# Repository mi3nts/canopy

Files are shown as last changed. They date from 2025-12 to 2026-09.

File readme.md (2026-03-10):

# CANOPY Community Avian and AirQuality Network for Observing Pollution Year-round
Contains firmware for the Community Avian and AirQuality Network for Observing Pollution Year-round(CANOPY)

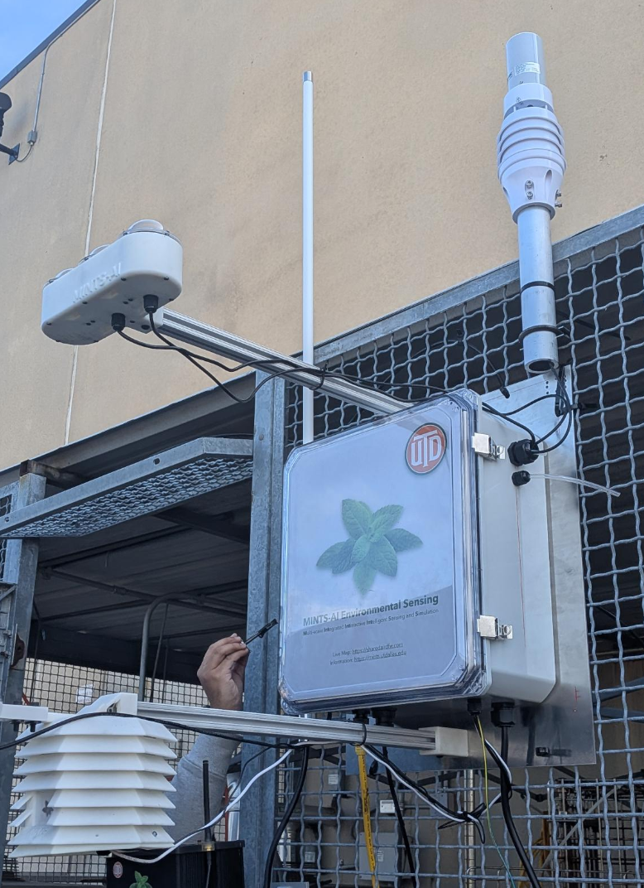
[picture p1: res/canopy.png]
Deployed Canopy


## Suggested Framework 

### 📋 Summary
This system design leverages an **Odroid** as a powerful Edge IoT node, integrating local data collection, processing, and resilient cloud synchronization. All local services and custom sensor readers are managed via **Git repositories** for version control and streamlined deployments. The system ensures continuous operation during internet outages by storing data locally and syncing to the cloud when connectivity is restored, while also publishing live data to the cloud via MQTT.

---

## Electrical Data Parts List
- **Raspberry Pi Zero 2W** (on [Dream V2.0 PCB Board](https://github.com/mi3nts/PCBMints2025) or later)
    - OPC-N3 
    - SJH-5A Methane Sensor (Not working on Dream V2.0 or earlier)
    - BME280 
    - IPS7100
    - COZIR AH-E-1
- **2x Odroid N2**
    - RS-FSXCS Anemometer
    - AS7265X
    - LTR390
    - SEN0463 Radiation sensor
    - 2x G-MOUSE USB GPS
    - USB Camera
    - USB Microphone
- **2x Arduino Boards**
    - One for managing the relays (receives input from odroidHeartbeat.py)
        - Ensure step up to 5V if board outputs 3.3V
    - One for digitalizing analog outputs from SEN0463

---

## Data Management
- **Git-Managed Dockerized Sensor Readers**: Python containers pulled from Git, reading sensors and publishing data via MQTT.
- **Git-Managed Local Services**:
  - **Mosquitto (MQTT Broker)**: Manages local messaging.
  - **Node-RED**: Handles data routing, automation, and local storage to InfluxDB.
  - **InfluxDB (Local)**: Buffers time-series data at the edge.
  - **Telegraf**: Continuously syncs local InfluxDB data to Cloud InfluxDB.
  - **Grafana**: Provides edge visualization for real-time monitoring without relying on cloud access.
- **Cloud Backend**: Centralized Node-RED, InfluxDB, and Grafana for real-time processing, long-term storage, and visualization.

---

### 🌐 Data Flow
1. Sensors connected to Odroid are read by Dockerized Python sensor readers deployed from Git - The current repo.
2. Sensor data is published to:
   - **Local MQTT Broker** for edge processing.
   - **Cloud MQTT Broker** for real-time cloud ingestion.
3. Node-RED (Edge) subscribes to local MQTT, processes data, and stores it in local InfluxDB.
4. Telegraf syncs buffered data from local InfluxDB to Cloud InfluxDB.
5. Cloud Node-RED and Grafana handle advanced workflows and visualization.

---

### 🛡️ Key Features
- **Git-Managed Deployments**: Version control for all services and sensor readers.
- **Offline Resilience**: Full functionality without internet.
- **Live Data Streaming**: Real-time data published to cloud via MQTT.
- **Automated Cloud Sync**: Telegraf ensures data consistency between edge and cloud.
- **Modular & Scalable**: Docker-based deployment for easy management.
- **Flexible Automation**: Node-RED enables custom logic and integrations.

---

## 🚀 Deployment Steps
1. Clone Git repositories for local services and sensor readers.
2. Deploy Docker Compose stack on Odroid (MQTT, Node-RED, InfluxDB, Telegraf, Grafana).
3. Run sensor reader containers from Git.
4. Configure Node-RED flows for data handling.
5. Set up Telegraf for continuous cloud sync.
6. Deploy local Grafana for edge-based dashboards and visualization.
7. Access cloud Node-RED and Grafana for real-time monitoring and dashboards.

### Odroid N2 Pinout Connection
- **Connection for 1B
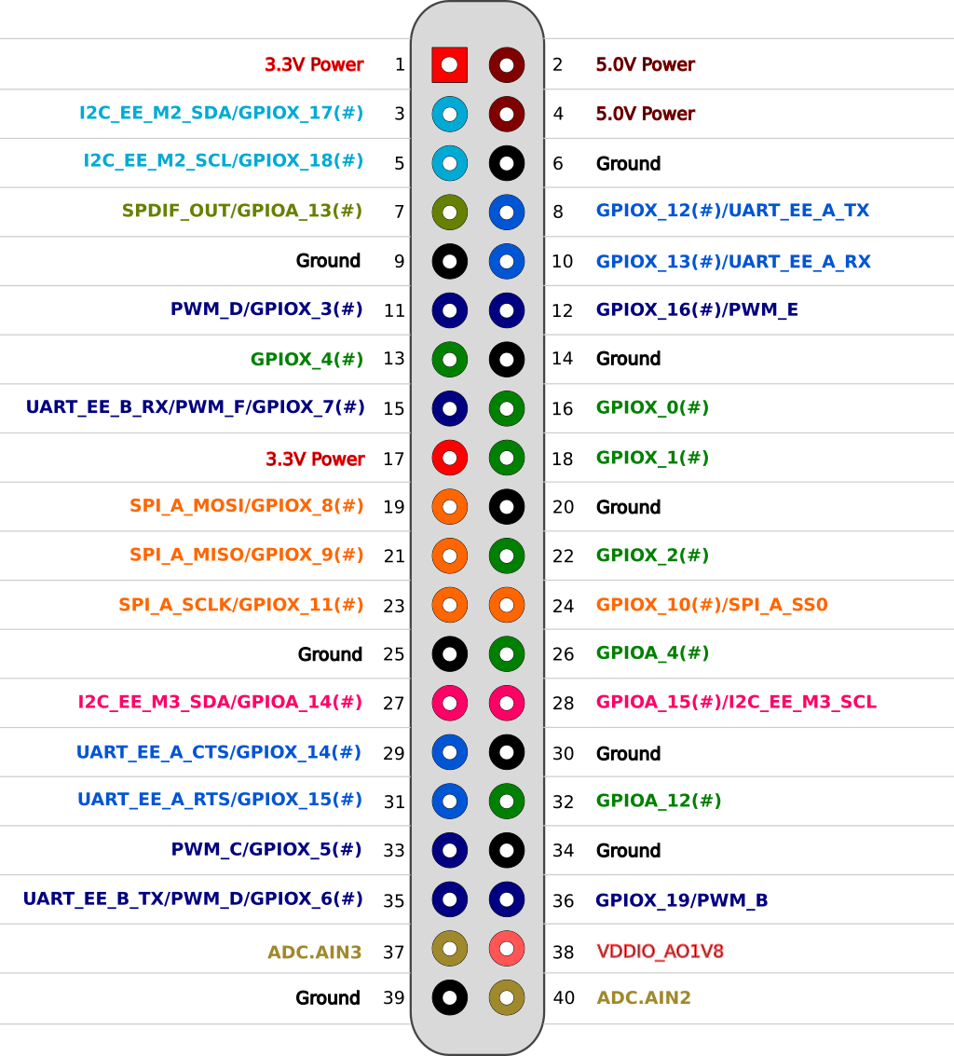
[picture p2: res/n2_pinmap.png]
Pinout Diagram
-

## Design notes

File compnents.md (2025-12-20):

# Components

## Main Compute Units 

- **Odroid N2+**

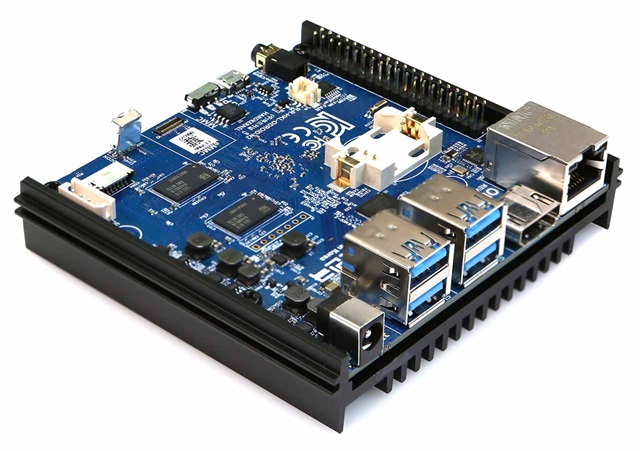
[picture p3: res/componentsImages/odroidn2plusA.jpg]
Odroid N2+
  

- **XIAO ESP32 S3**
  
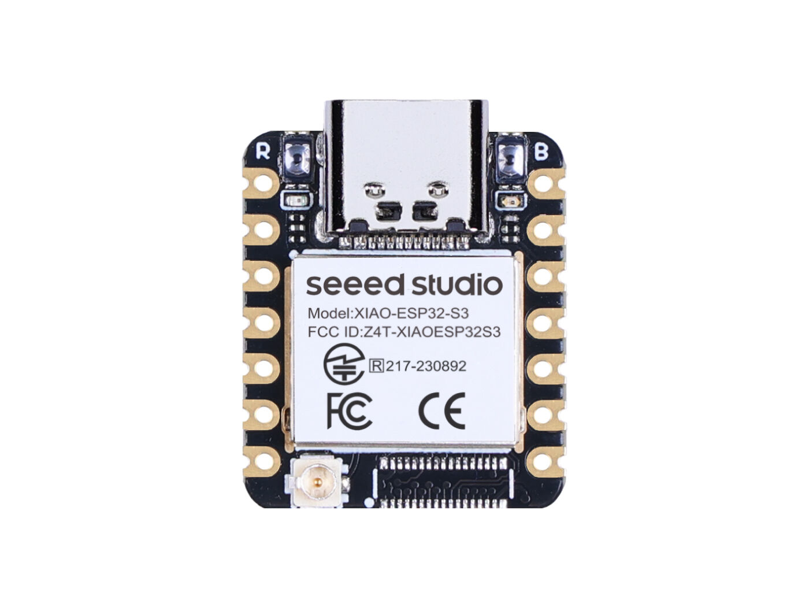
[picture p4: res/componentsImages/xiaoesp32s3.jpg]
XIAO ESP32 S3
   

- **Arduino Nano 33 BLE** 
  
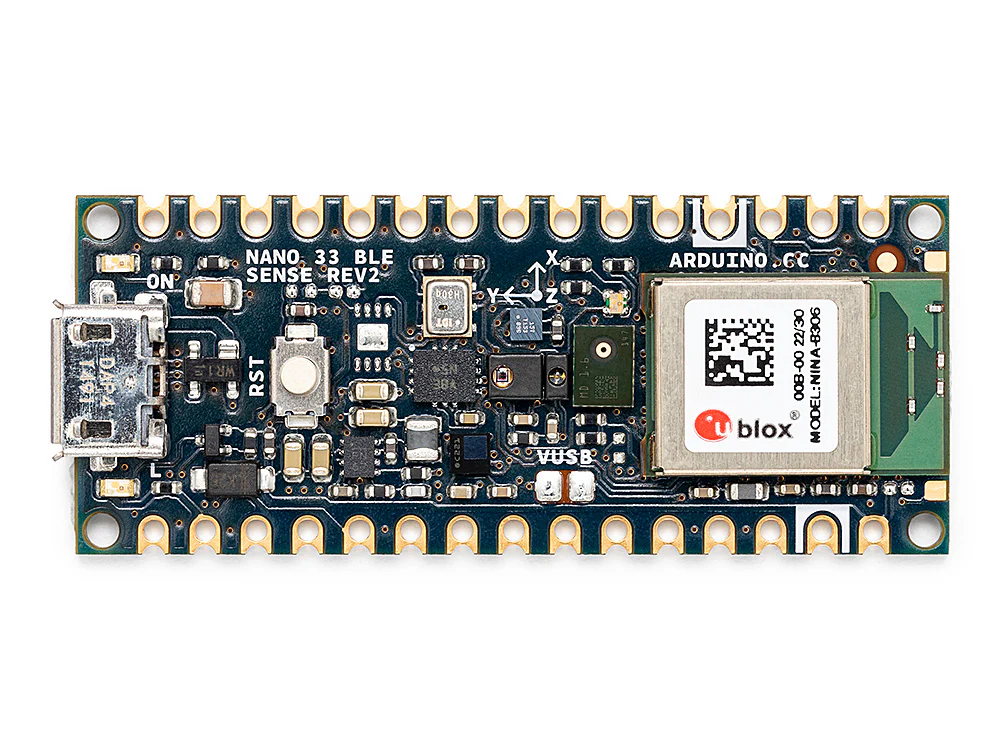
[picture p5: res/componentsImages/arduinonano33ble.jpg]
Arduino Nano 33 BLE
  

## Sensor Modules

- **DFRobot SEN0463** 
  
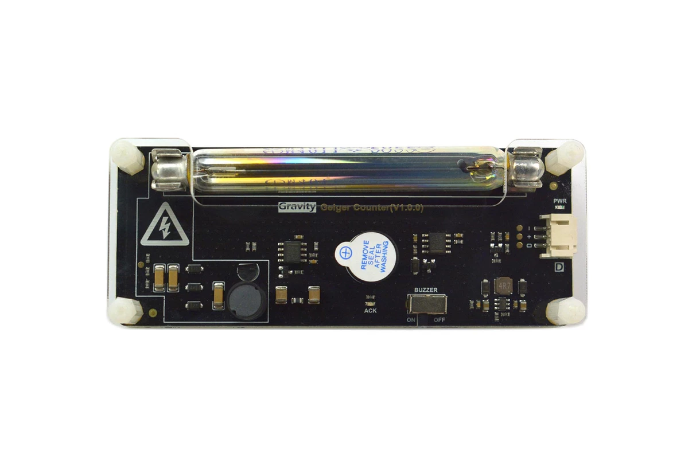
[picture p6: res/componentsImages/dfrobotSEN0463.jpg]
DFRobot SEN0463
   

- **Ozone Sensor** 
  
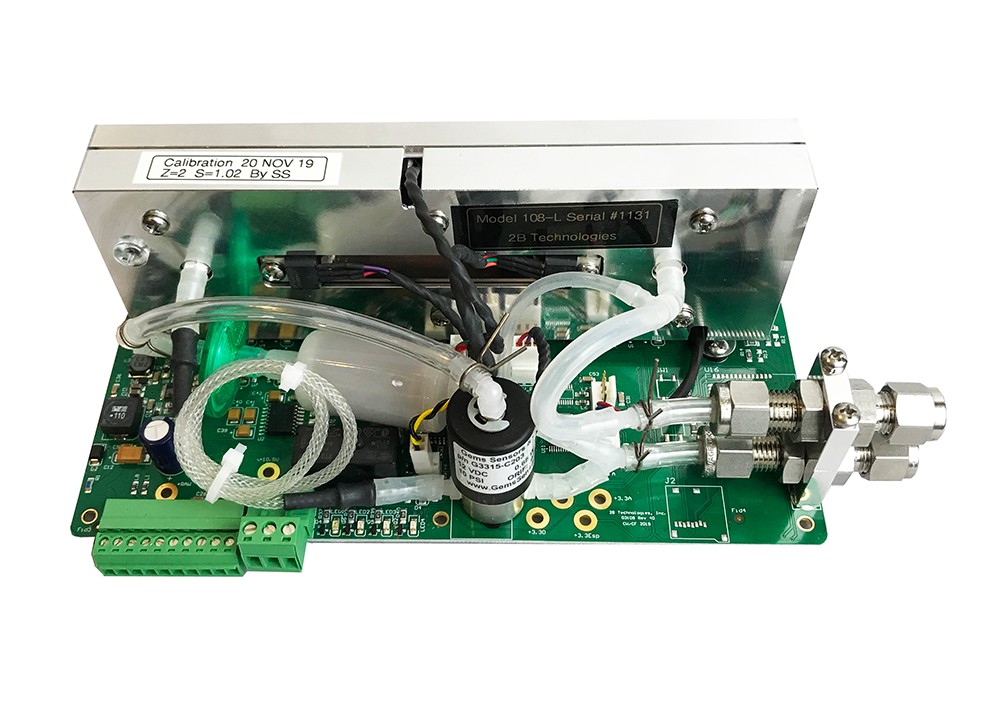
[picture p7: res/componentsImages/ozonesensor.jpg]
Ozone Sensor
  

- **GPS Module** 
  
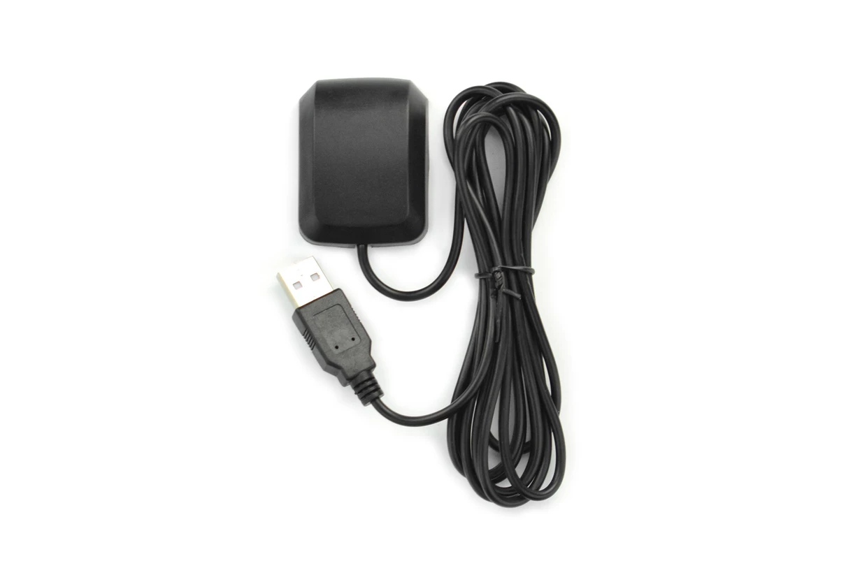
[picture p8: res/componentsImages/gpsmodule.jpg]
GPS Module
  

 ## Network Modules

- **Network Switch** (4 port) 
  
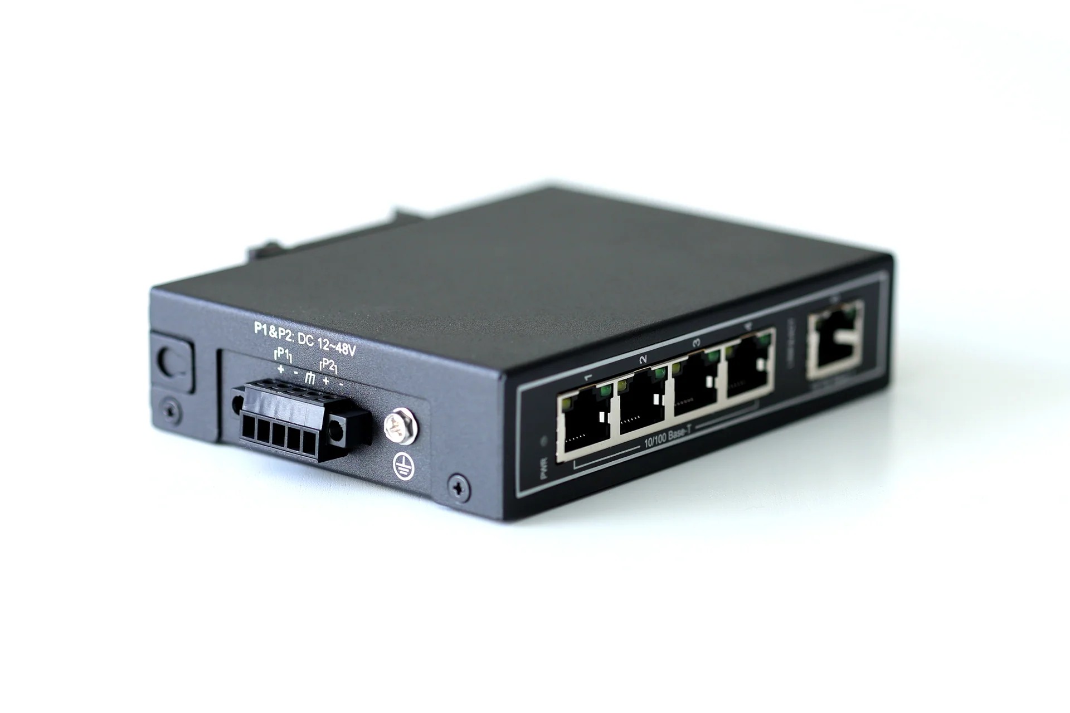
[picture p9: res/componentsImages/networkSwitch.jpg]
Network Switch
  

- **LoRaWAN Gateway** 
  
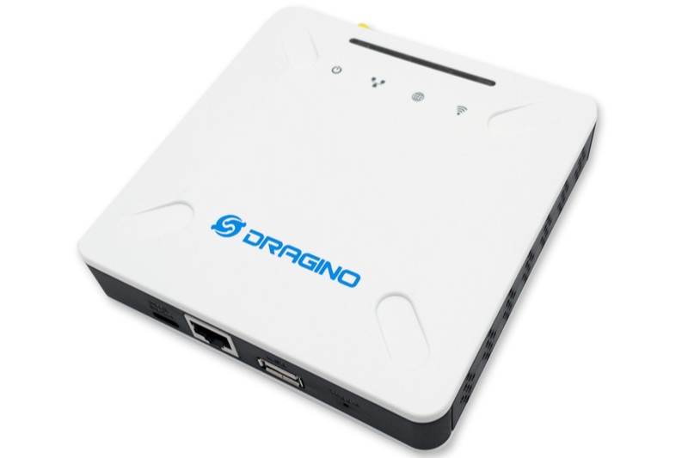
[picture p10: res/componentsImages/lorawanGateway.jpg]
LoRaWAN Gateway
  

## Power Modules
- **12V 3A AC to DC Power Supply** 
  
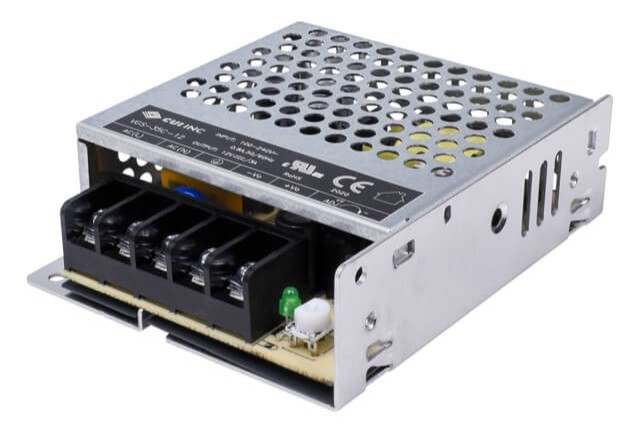
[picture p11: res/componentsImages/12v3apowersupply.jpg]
12V 3A AC to DC Power Supply
  

- **5V 5A AC to DC Power Supply** 
  
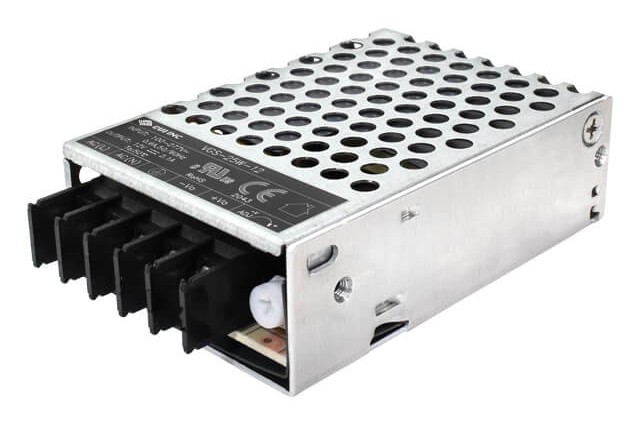
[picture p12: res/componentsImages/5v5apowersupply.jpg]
5V 5A AC to DC Power Supply
  

- **Solid State Relay 4 Channel** 
  
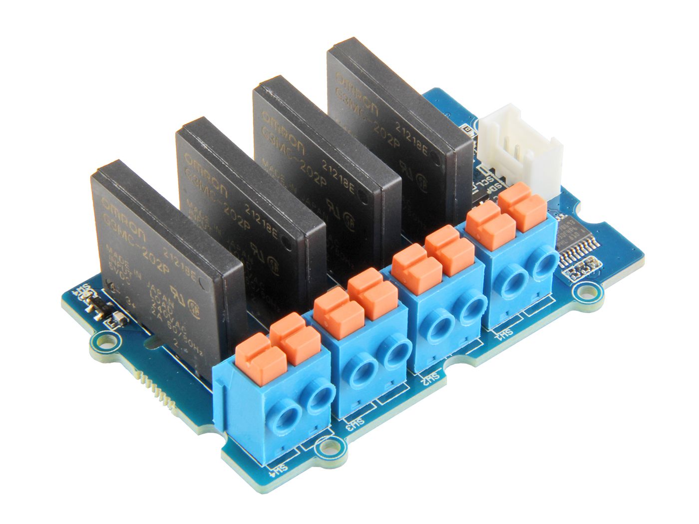
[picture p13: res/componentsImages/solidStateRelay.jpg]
Solid State Relay 4 Channel


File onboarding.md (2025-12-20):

# 🚀 Odroid N2+ Onboarding Guide

## 📥 OS Installation on SD Card  
1. Download the Odroid N2+ OS from [this link](https://wiki.odroid.com/odroid-n2/os_images/ubuntu/20220228).  
2. Use [Etcher](https://etcher.balena.io/) to flash the image onto your SD card.

---

## 👤 User Account Setup
1. Connect to the Odroid via a [UART Module](https://ameridroid.com/products/usb-uart-2-module-kit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).
2. Login using default credentials:
   - **Username:** `odroid`
   - **Password:** `odroid`
3. Create a new user:
   ```bash
   sudo adduser teamlary
   ```
4. Grant sudo privileges:
   ```bash
   sudo usermod -aG sudo teamlary
   ```
5. Switch to the new user:
   ```bash
   su teamlary
   ```
6. Create default directories:
   ```bash
   xdg-user-dirs-update
   ```
7. Verify sudo access:
   ```bash
   sudo whoami
   ```
   Expected output: `root`
8. Change the user password:
   ```bash
   passwd
   ```
9. Remove the default `odroid` user:
   ```bash
   sudo su
   userdel odroid
   userdel -r odroid
   ```

---

## 🕒 Time Zone & Clock Configuration

Ensure an RTC module is installed. Perform the following on all Linux-based MINTS nodes:

1. Check current time settings:
   ```bash
   timedatectl status
   ```
2. Set system time zone to UTC:
   ```bash
   timedatectl set-timezone UTC
   ```
3. Configure RTC to use UTC:
   ```bash
   timedatectl set-local-rtc 0
   ```
4. Enable NTP synchronization:
   ```bash
   timedatectl set-ntp true
   ```

✅ After completion, verify synchronization using:
```bash
timedatectl status
```

*Reference:* [Tecmint Guide](https://www.tecmint.com/set-time-timezone-and-synchronize-time-using-timedatectl-command/)

### 🌐 No Internet? Sync Time from RTC
If no internet is available, configure automatic RTC sync via `/etc/rc.local`:

1. Edit the file:
   ```bash
   sudo nano /etc/rc.local
   ```

2. Add the following script:

   ```bash
   #!/bin/bash

   if [ -f /aafirstboot ]; then 
       /aafirstboot start
   fi

   if ping -c 1 8.8.8.8 >/dev/null 2>&1; then
       echo "$(date): Internet detected - Syncing system clock..."
       sudo systemctl restart systemd-timesyncd
       sleep 10

       if timedatectl | grep -q "System clock synchronized: yes"; then
           echo "$(date): Writing system time to RTC..."
           hwclock -w
       else
           echo "$(date): System clock not synced yet. Skipping RTC update." >> /var/log/time_sync.log
       fi
   else
       echo "No internet connection: Syncing system time from RTC..."
       hwclock -s
   fi

   exit 0
   ```

**Behavior:**
- 🌐 **With Internet:** Sync system clock via NTP and update RTC.
- 🚫 **Without Internet:** Restore system clock from RTC.

---

## 🌐 DWAgent Remote Access Setup

### 📥 Installation
1. On your DWService account, create a new agent.
2. Download the installer for Ubuntu:
   ```bash
   wget https://www.dwservice.net/download/dwagent.sh
   chmod +x dwagent.sh 
   sudo ./dwagent.sh
   ```
3. During installation, select **Installer Code** and enter the provided code to register the agent.
4. Complete the setup by copying the agent code to your system.

### ❌ Uninstallation
To remove DWAgent:
```bash
sudo bash /usr/share/dwagent/native/uninstall
```
Follow the on-screen instructions to complete the uninstallation.

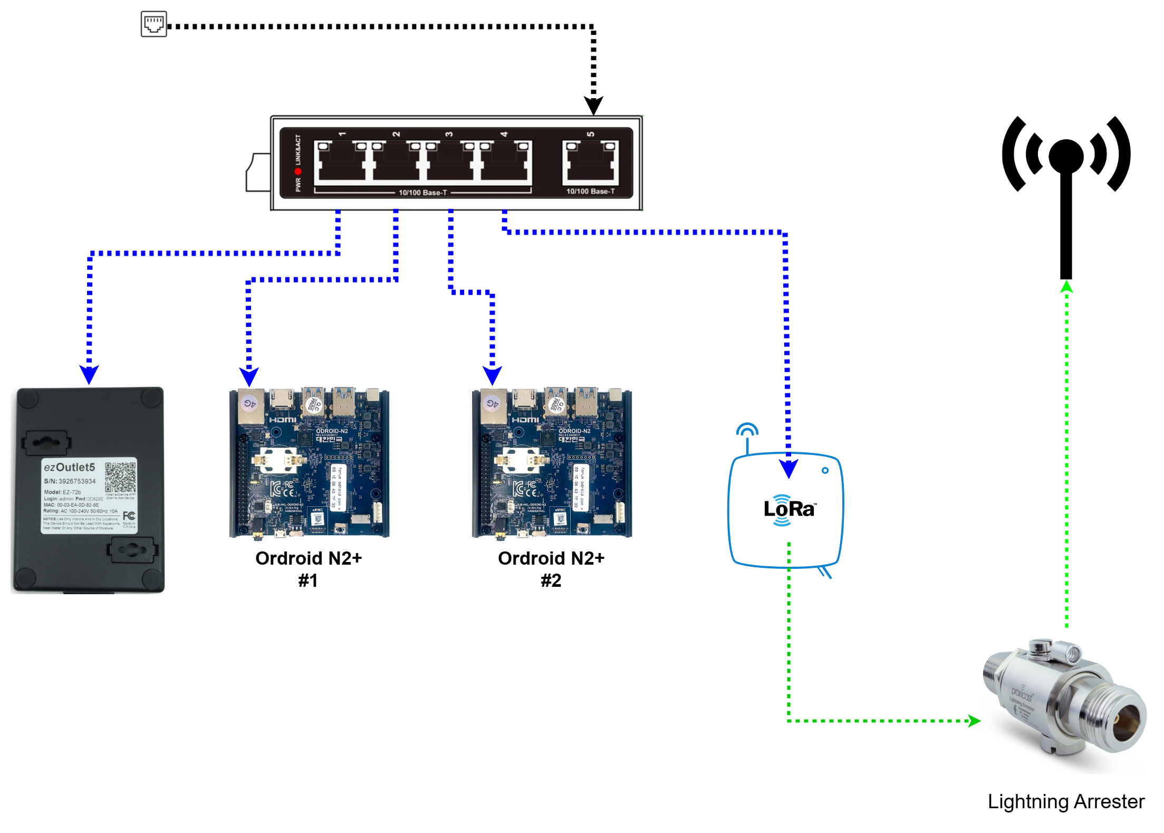
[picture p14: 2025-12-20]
res/CanopyNetworkDiagram.drawio.png

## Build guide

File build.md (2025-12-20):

# Build 

## Components
| Type | Component Name | Quantity | Canopy 1 | Canopy 2 | Canopy 3 |
| :--- | :--- | :---: | :---: | :---: | :---: |
| **Compute Modules** | [**Odroid N2+**](https://www.hardkernel.com/shop/odroid-n2-with-4gbyte-ram-2/) | 2 | ✅ | ✅ | ✅ |
|  | [**Arduino Nano 33 BLE**](https://store.arduino.cc/products/nano-33-ble-sense-rev2) | 1 | ✅ | ✅ | ❌ |
|  | [**XIAO ESP32 S3**](https://www.seeedstudio.com/XIAO-ESP32S3-p-5627.html) | 1 | ✅ | ✅ | ❌ |
| **Sensor Modules** | [**DFRobot SEN0463**](https://www.dfrobot.com/product-2547.html) | 1 | ✅ | ✅ | ❌ |
|  | [**Ozone Sensor**](https://2btech.io/items/industrial-ozone-monitors/model-108-l-ozone-monitor/) | 1 | ✅ | ✅ | ✅ |
| **Network Modules** | [**Network Switch** (4 port)](https://wiwav.com/products/wdh-5et-dc) | 1 | ✅ | ✅ | ✅ |
|  | [**LoRaWAN Gateway**](https://www.dragino.com/products/lora-lorawan-gateway/item/228-lps8v2.html) | 1 | ✅ | ✅ | ✅ |
| **Power Modules** | [**12V 3A AC to DC Power Supply**](https://www.digikey.com/en/products/detail/cui-inc/vgs-35c-12/13538494) | 3 | ✅ | ✅ | ✅ |
|  | [**5V 5A AC to DC Power Supply**](https://www.digikey.com/en/products/detail/cui-inc/VGS-25W-5/13981829) | 2 | ✅ | ✅ | ✅ |
|  | [**Solid State Relay 4 Channel**](https://www.seeedstudio.com/Grove-4-Channel-Solid-State-Relay.html) | 1 | ✅ | ✅ | ❌ |
|  | [**ezOutlet5**](https://www.proxicast.com/shopping/ezoutlet5.html) | 1 | ✅ | ✅ | ✅ |
| **Glands** | [**Power Gland**](https://www.digikey.com/en/products/detail/adam-tech/PG-2-3/10000000) | 1 | ✅ | ✅ | ✅ |
|  | [**Ethernet Gland**](https://www.digikey.com/en/products/detail/conxall-switchcraft/dcp-rj6st-f/3909464) | 1 | ✅ | ✅ | ✅ |
| **CNC & 3D Printed Parts** | **Acrylic Base** | 1 | ✅ | ✅ | ✅ |
|  | **Odroid N2+ Bases** | 2 | ✅ | ✅ | ✅ |
|  | **GPS Enclosure** | 1 | ✅ | ✅ | ✅ |
|  | **Geiger(SEN0463) Enclosure** | 1 | ✅ | ✅ | ⏳ |
|  | **Ozone Pump Base** | 1 | ✅ | ✅ | ✅ |
|  | **LoRaWAN Gateway Holder** | 1 | ✅ | ✅ | ✅ |
|  | **ezOutlet5 Holder** | 1 | ✅ | ✅ | ✅ |
|  | **5V Power Supply Base** | 2 | ✅ | ✅ | ✅ |
|  | **12V Power Supply Base** | 3 | ✅ | ✅ | ✅ |
|  | **Solid State Relay Base** | 1 | ✅ | ✅ | ❌ |
|  | **Lightning Arrester Enclosure** | 1 | ✅ | ✅ | ✅ |
| **Miscellaneous** | [**Lightning Arrestor**](https://www.waveform.com/products/sma-lightning-arrestor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) | 1 | ✅ | ✅ | ✅ |
|  | [**GPS Module**](https://www.dfrobot.com/product-2212.html?srsltid=AfmBOopC3ACS4fteI6YBTIDWjCWQ0hfJIGSxyhN_UdGwQtrTQll43zKa) | 2 | ✅ | ✅ | ✅ |
|  | [**Ozone Pump**](https://knf.com/en/us/solutions/pumps/series/diaphragm-gas-pump-nmp-830) | 1 | ✅ | ✅ | ✅ |

## Wires and Cables
| Type | Component Name | Wire type | Length | Color | Quantity | Canopy 1 | Canopy 2 | Canopy 3 |
|:---|:---|:---:|:---:|:-----:|:---:|:---:|:---:|:---:|
| **Wires and Cables** | **AC Earth Wires** | 16AWG | 15cm | 🟢 Green | 2 | ✅ | ✅ | ✅ |
| | | 16AWG | 25cm | 🟢 Green | 1 | ✅ | ✅ | ✅ |
| | **AC Neutral Wires** | 16AWG | 15cm | ⚪ White | 2 | ✅ | ✅ | ✅ |
| | | 16AWG | 25cm | ⚪ White | 1 | ✅ | ✅ | ✅ |
| | **AC Live Wires** | 16AWG | 25cm | ⚫ Black | 3 | ✅ | ✅ | ✅ |
| | **1 to 3 splitter 25cm**  | 16AWG | (10cm + 3x 15cm) | ⚫ Black | 1 | ✅ | ✅ | ✅ |
| | **DC Common Ground Wires**| 16AWG | 15cm | 🔵  Blue | 3 | ✅ | ✅ | ✅ |
| | | 16AWG | 20cm | 1 | 1 | ✅ | ✅ | ✅ |
| | **Solid State Relay Ground**| Thin Silicone Wires | 15cm | ⚫ Black | 1 | ✅ | ✅ | ❌ |
| | **Arduino Nano 33 BLE Ground** | Thin Silicone Wires | 25cm | ⚫ Black | 1 | ✅ | ✅ | ❌ |
| | **Arduino Nano 33 BLE Power** | Thin Silicone Wires | 25cm | 🔴 Red | 1 | ✅ | ✅ | ❌ |
| | **DC Power Cables** | - | Coaxial | - | 3 | ✅ | ✅ | ✅ |
| | **Ethernet Cables** | CAT6 | 30cm | - | 3 | ✅ | ✅ | ✅ |
| | | CAT6 | 60cm | - | 1 | ✅ | ✅ | ✅ |
| | | CAT6 | 90cm | - | 1 | ✅ | ✅ | ✅ |

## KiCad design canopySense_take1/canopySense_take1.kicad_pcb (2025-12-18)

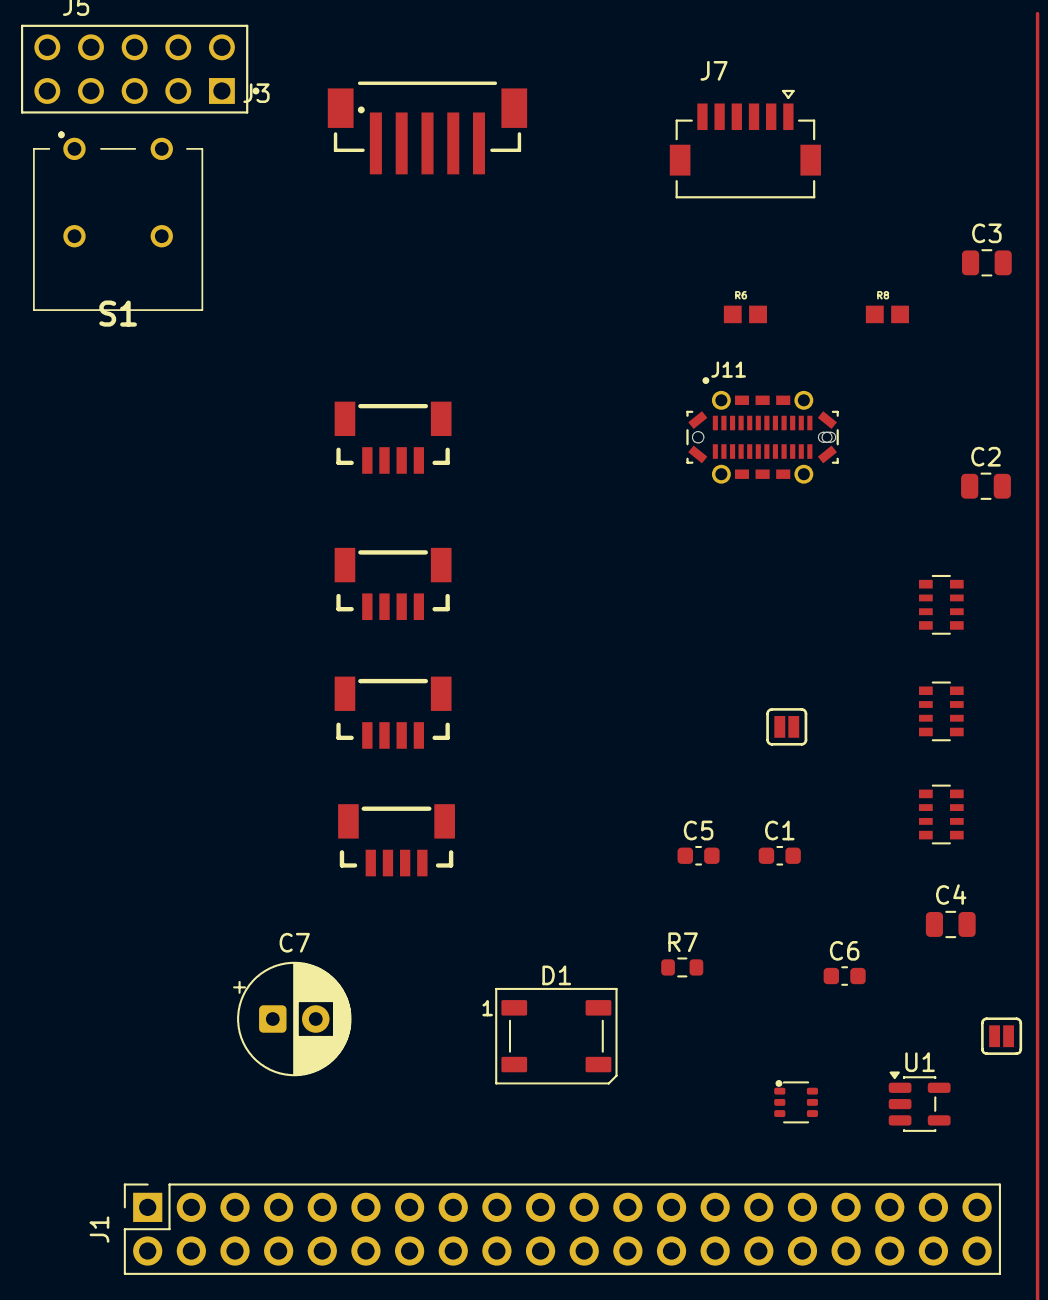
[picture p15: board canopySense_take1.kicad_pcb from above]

Board: 2 copper layers, 28 parts (0 on the bottom side), 26 nets, no tracks yet.

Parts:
C1, C5, C6: 0.1uF; C_0603_1608Metric
C2, C3, C4: 10uF; C_0805_2012Metric
C7: EEV107M010S9GAA; CP_Radial_D6.3mm_P2.50mm
D1: WS2812B_5050; LED_WS2812B_PLCC4_5.0x5.0mm_P3.2mm
J1: GPIO; PinSocket_2x20_P2.54mm_Vertical
J2, J4, J6: Qwiic_Vertical; JST_1x04_P1.0mm_Vertical_SMD
J3: 679305124022
J5: M20-7830542; HARWIN_M20-7830542
J7: 5013310607; MOLEX_5013310607
J11: 10132328-10011LF; AMPHENOL_10132328-10011LF
JP2, JP3: Jumper_2_NO
Q1: BSS138; SOT-363
R1, R2, R5: 10k; R_Array_Convex_4x0603
R6: RC0603FR-075K1L; RESC1607X60N
R7: 5.1k; R_0603_1608Metric
R8: RC0603FR-07330RL; RESC1607X60N
S1: AB11AH-FC; AB11AHFC
U1: AP2112K-3.3; SOT-23-5
j9: Qwiic_Vertical; JST_1x04_P1.0mm_Vertical_SMD

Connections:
+3V3: C2.1, J1.1, J1.17, J2.2, J5.3, J6.2, R1.2, R1.4, U1.1 (VIN), U1.3 (EN), j9.2
+5V: C4.1, C5.1, C6.1, C7.P, D1.1 (VDD), J1.2, J1.4, J3.1, J4.2, J7.1, JP2.2 (B), JP3.2 (B), R5.2, R5.4, S1.3
/5V_BUS_USB: J11.A4 (VBUS_A4), J11.A9 (VBUS_A9), J11.B4 (VBUS_B4), J11.B9 (VBUS_B9), S1.1
/BME_SCL: Q1.1 (S), R1.5
/BME_SDA: Q1.4 (S), R1.8
/GPIO2/SDA1: J1.3, j9.3
/GPIO3/SCL1: J1.5, j9.4
/GPIO5/SDA5: J1.29, J2.3, Q1.3 (D), R1.3
/GPIO6/SCL5: J1.31, J2.4, Q1.6 (D), R1.1
/GPIO8/SPI0.CE0: J1.24, J7.5
/GPIO9/SPI0.MISO: J1.21, J7.3
/GPIO10/SPI0.MOSI: J1.19, J7.4
/GPIO11/SPI0.SCLK: J1.23, J7.2
/GPIO14/TXD0: J1.8, J5.5, J6.3
/GPIO15/RXD0: J1.10, J5.7, J6.4
/GPIO22/SCL3: J1.15, J3.3, J4.4
/GPIO23/SDA4: J1.16, R5.1
/GPIO24/SCL4: J1.18, R5.3
/GPIO27/SDA3: J1.13, J3.2, J4.3
/INA_ADD0: JP2.1 (A), R2.5
/INA_ADD1: JP3.1 (A), R2.8
BME_3V3: C1.1, C3.1, Q1.2 (G), Q1.5 (G), R1.6, R1.7, U1.5 (VOUT)
GND: C1.2, C2.2, C3.2, C4.2, C5.2, C6.2, C7.N, D1.3 (VSS), J1.6, J1.9, J1.14, J1.20, J1.25, J1.30, J1.34, J1.39, J2.1, J3.4, J3.5, J4.1, J5.1, J5.4, J5.6, J6.1, J7.6, J11.1 (SHIELD), J11.2 (SHIELD__1), J11.3 (SHIELD__2), J11.4 (SHIELD__3), J11.5 (SHIELD__4), J11.6 (SHIELD__5), J11.7 (SHIELD__6), J11.8 (SHIELD__7), J11.9 (SHIELD__8), J11.10 (SHIELD__9), J11.11 (SHIELD__10), J11.12 (SHIELD__11), J11.13 (SHIELD__12), J11.14 (SHIELD__13), J11.A1 (GND_A1), J11.A12 (GND_A12), J11.B1 (GND_B1), J11.B12 (GND_B12), R2.6, R2.7, R6.1, R7.1, U1.2 (GND), j9.1
unnamed: D1.4 (DIN), R8.1
unnamed: J11.A5 (CC1), R7.2
unnamed: J11.B5 (CC2), R6.2

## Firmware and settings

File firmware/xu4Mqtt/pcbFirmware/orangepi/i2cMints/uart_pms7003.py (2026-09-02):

"""
PMS7003 (Plantower) UART driver.

Target: Linux SBC, e.g. Orange Pi Zero 2W (Allwinner H618, Armbian).
Protocol: 9600 8N1, 32-byte big-endian frames, header 0x42 0x4D.

Frame layout (byte offsets within the 32-byte frame):
     0..1   0x42 0x4D
     2..3   frame length field (== 28)
     4..9   PM1.0 / PM2.5 / PM10  CF=1 ("standard", factory calibration)
    10..15  PM1.0 / PM2.5 / PM10  atmospheric
    16..27  particle counts > 0.3, 0.5, 1.0, 2.5, 5.0, 10.0 um per 0.1 L
    28      version
    29      error code
    30..31  checksum = sum(frame[0:30])

Notes on measurement validity:
  - The CF=1 values are the raw factory-calibrated output; the "atmospheric"
    values apply an additional density correction. They are identical below
    roughly 100 ug/m3 and diverge above it. Report which one you logged.
  - The optical counts are NOT true bin counts: they are cumulative
    (> threshold), and the 6 channels are interpolated from a smaller number
    of physically resolved bins. Treat pc_* as semi-quantitative.
  - Allow >= 30 s of fan runtime before trusting a reading.
"""

from __future__ import annotations

import datetime
import struct
import time
from collections import OrderedDict
from typing import Optional

import serial


class PMS7003:
    BODY_LEN = 30                 # bytes following the 0x42 0x4D header
    FRAME_LENGTH_FIELD = 28       # expected value of bytes 2..3

    CMD_PASSIVE = bytes((0x42, 0x4D, 0xE1, 0x00, 0x00, 0x01, 0x70))
    CMD_ACTIVE  = bytes((0x42, 0x4D, 0xE1, 0x00, 0x01, 0x01, 0x71))
    CMD_REQUEST = bytes((0x42, 0x4D, 0xE2, 0x00, 0x00, 0x01, 0x71))
    CMD_SLEEP   = bytes((0x42, 0x4D, 0xE4, 0x00, 0x00, 0x01, 0x73))
    CMD_WAKE    = bytes((0x42, 0x4D, 0xE4, 0x00, 0x01, 0x01, 0x74))

    WARMUP_S = 30.0

    # Keys of the original MINTS schema, in order. Used to keep CSV headers
    # stable against an existing archive when extra fields are added here.
    MINTS_KEYS = (
        "dateTime",
        "pm1_0_standard", "pm2_5_standard", "pm10_0_standard",
        "pm1_0_atm", "pm2_5_atm", "pm10_0_atm",
        "pc_0_3", "pc_0_5", "pc_1_0", "pc_2_5", "pc_5_0", "pc_10_0",
    )

    def __init__(self, port, baudrate=9600, timeout=1.0,
                 passive=True, utc=False, debug=False):
        self.port = port
        self.baudrate = baudrate
        self.timeout = timeout
        self.passive = passive
        self.utc = utc
        self.debug = debug
        self.ser: Optional[serial.Serial] = None
        self._fan_started: Optional[float] = None
        self.last_datetime: Optional[datetime.datetime] = None

    # accept the original keyword name used by the MINTS readers
    @classmethod
    def from_mints(cls, serial_port, **kwargs):
        return cls(serial_port, **kwargs)

    def _now(self) -> datetime.datetime:
        """Naive datetime, matching the MINTS convention of str(datetime)."""
        if self.utc:
            return datetime.datetime.now(datetime.timezone.utc).replace(tzinfo=None)
        return datetime.datetime.now()

    # ---------------------------------------------------------------- setup

    def _log(self, msg):
        if self.debug:
            print(f"[PMS7003:{self.port}] {msg}")

    def open(self, retries=10, backoff=1.0) -> bool:
        """Open the port. Returns True on success. Idempotent."""
        for attempt in range(1, retries + 1):
            try:
                if self.ser is not None:
                    self.ser.close()
                self.ser = serial.Serial(
                    self.port,
                    baudrate=self.baudrate,
                    bytesize=serial.EIGHTBITS,
                    parity=serial.PARITY_NONE,
                    stopbits=serial.STOPBITS_ONE,
                    timeout=self.timeout,
                    write_timeout=self.timeout,
                )
                if not self.ser.is_open:
                    self.ser.open()
                self.ser.reset_input_buffer()
                self.ser.reset_output_buffer()
                self._fan_started = time.monotonic()
                if self.passive:
                    self.set_passive()
                self._log(f"connected (attempt {attempt})")
                return True
            except (serial.SerialException, OSError) as exc:
                self._log(f"open attempt {attempt}/{retries} failed: {exc}")
                self.ser = None
                time.sleep(backoff)
        return False

    # keep the original name working
    initiate = open

    def close(self):
        if self.ser is not None:
            try:
                self.ser.close()
            except Exception:
                pass
        self.ser = None

    def __enter__(self):
        if not self.open():
            raise serial.SerialException(f"cannot open {self.port}")
        return self

    def __exit__(self, *exc):
        self.close()

    # -------------------------------------------------------------- commands

    def _write(self, cmd: bytes):
        if self.ser is None or not self.ser.is_open:
            raise serial.SerialException("port not open")
        self.ser.write(cmd)
        self.ser.flush()

    def set_passive(self):
        self._write(self.CMD_PASSIVE)
        self.passive = True
        time.sleep(0.1)
        self.ser.reset_input_buffer()   # drop the command ACK / in-flight frame

    def set_active(self):
        self._write(self.CMD_ACTIVE)
        self.passive = False
        time.sleep(0.1)
        self.ser.reset_input_buffer()

    def sleep(self):
        """Stop fan and laser. Extends the ~8000 h laser lifetime."""
        self._write(self.CMD_SLEEP)
        self._fan_started = None

    def wake(self):
        self._write(self.CMD_WAKE)
        self._fan_started = time.monotonic()
        time.sleep(0.1)
        self.ser.reset_input_buffer()

    @property
    def warm(self) -> bool:
        """True once the fan has run long enough for the datasheet-stable regime."""
        return (self._fan_started is not None
                and time.monotonic() - self._fan_started >= self.WARMUP_S)

    def wait_warm(self):
        if self._fan_started is None:
            return
        remaining = self.WARMUP_S - (time.monotonic() - self._fan_started)
        if remaining > 0:
            time.sleep(remaining)

    # ------------------------------------------------------------ frame read

    def _sync(self, deadline) -> bool:
        """Byte-wise search for 0x42 0x4D. Immune to odd-boundary desync."""
        prev = None
        while time.monotonic() < deadline:
            b = self.ser.read(1)
            if not b:
                continue
            cur = b[0]
            if prev == 0x42 and cur == 0x4D:
                return True
            prev = cur
        return False

    def _read_exact(self, n, deadline) -> Optional[bytes]:
        buf = bytearray()
        while len(buf) < n and time.monotonic() < deadline:
            chunk = self.ser.read(n - len(buf))
            if chunk:
                buf.extend(chunk)
        return bytes(buf) if len(buf) == n else None

    def read(self, max_wait=3.0, reconnect=True) -> Optional[OrderedDict]:
        """
        Return one validated measurement, or None.

        In passive mode a read request is issued and the reply is consumed, so
        the sample is always fresh. In active mode the input buffer is flushed
        first for the same reason.
        """
        if self.ser is None or not self.ser.is_open:
            if not (reconnect and self.open(retries=1)):
                return None

        deadline = time.monotonic() + max_wait
        try:
            if self.passive:
                self.ser.reset_input_buffer()
                self._write(self.CMD_REQUEST)
            else:
                self.ser.reset_input_buffer()

            if not self._sync(deadline):
                self._log("no header within timeout")
                return None

            body = self._read_exact(self.BODY_LEN, deadline)
            if body is None:
                self._log("truncated frame")
                return None
            # timestamp at frame arrival, not at request time
            dt = self._now()

        except (serial.SerialException, OSError) as exc:
            self._log(f"serial error: {exc}")
            self.close()
            if reconnect and self.open(retries=1):
                return None
            return None

        return self._parse(body)

    def _parse(self, body: bytes) -> Optional[OrderedDict]:
        frame_len = (body[0] << 8) | body[1]
        if frame_len != self.FRAME_LENGTH_FIELD:
            self._log(f"unexpected frame length field: {frame_len}")
            return None

        checksum = 0x42 + 0x4D + sum(body[:28])
        expected = (body[28] << 8) | body[29]
        if checksum != expected:
            self._log(f"checksum mismatch: {checksum:#06x} != {expected:#06x}")
            return None

        vals = struct.unpack(">12H", body[2:26])
        version, error_code = body[26], body[27]

        return OrderedDict((
            ("dateTime",        datetime.datetime.now(datetime.timezone.utc).isoformat()),
            ("pm1_0_standard",  float(vals[0])),
            ("pm2_5_standard",  float(vals[1])),
            ("pm10_0_standard", float(vals[2])),
            ("pm1_0_atm",       float(vals[3])),
            ("pm2_5_atm",       float(vals[4])),
            ("pm10_0_atm",      float(vals[5])),
            ("pc_0_3",          int(vals[6])),
            ("pc_0_5",          int(vals[7])),
            ("pc_1_0",          int(vals[8])),
            ("pc_2_5",          int(vals[9])),
            ("pc_5_0",          int(vals[10])),
            ("pc_10_0",         int(vals[11])),
            ("version",         int(version)),
            ("error_code",      int(error_code)),
            ("warm",            self.warm),
        ))


if __name__ == "__main__":
    import sys

    port = sys.argv[1] if len(sys.argv) > 1 else "/dev/ttyS5"

    with PMS7003(port, passive=True, debug=True) as pms:
        print("warming up...")
        pms.wait_warm()
        while True:
            sample = pms.read()
            if sample is None:
                print("read failed")
            else:
                print(f"{sample['dateTime']}  "
                      f"PM1.0={sample['pm1_0_atm']:6.1f}  "
                      f"PM2.5={sample['pm2_5_atm']:6.1f}  "
                      f"PM10={sample['pm10_0_atm']:6.1f} ug/m3  "
                      f"err={sample['error_code']}")
            time.sleep(1.0)

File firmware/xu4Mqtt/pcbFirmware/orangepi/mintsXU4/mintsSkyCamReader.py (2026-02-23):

from datetime import timezone
import time
import os
import datetime
import numpy as np
import pickle
from skimage import io, color
import cv2
from collections import OrderedDict
# import gspread
# from oauth2client.service_account import ServiceAccountCredentials


# def main():
#
#     dataFolder    = '../../../../data/'
#     subFolder     = dataFolder + "webCamSnaps/"
#
#     onboardCapture = True
#     currentImage,imagePath =  getSnapShot(subFolder)
#     # currentImage,imagePath =  getSnapShotFromPath(pathIn)
#
#     start = time.time()
#     modelName = 'naiveBayesModel.sav'
#
#     oneDImage, imageShape = generateFeatures(currentImage,imagePath)
#     print("Loading Classifier")
#
#     loadedModel = pickle.load(open(modelName, 'rb'))
#     print("Done Loading")
#     predictionBinary,prediction = getPredictionMatrix(loadedModel,oneDImage)
#
#     print("Writing Resulting Images ...")
#     binaryImage = writeBinaryImage(predictionBinary,imageShape,imagePath,onboardCapture)
#     resultsOut  = getResults(currentImage,binaryImage,predictionBinary,prediction,imagePath)
#     print(str(resultsOut))
#     # wks.append_row(resultsOut)
#
#
#     ## Now the Focus will


def getResultsXU4002(originalImage,binaryImage,predictionBinary,prediction,imagePath,dateTime):

    onlyCloud          = getCloudOnlyImage(originalImage,binaryImage)
    onlySky            = getSkyOnlyImage(originalImage,binaryImage)

    cloudPercentage    = (sum(predictionBinary)/len(predictionBinary))*100

    percentageAccuracy = sum(abs(prediction-.5)*200)/len(prediction)
    #
    colorSumBlueAll    = originalImage[:,:,0].sum()
    colorSumGreenAll   = originalImage[:,:,1].sum()
    colorSumRedAll     = originalImage[:,:,2].sum()

    dimSize = np.shape(originalImage)

    numOfPixels        = dimSize[0]*dimSize[1]

    averageBlueAll     = colorSumBlueAll/numOfPixels
    averageGreenAll    = colorSumGreenAll/numOfPixels
    averageRedAll      = colorSumRedAll/numOfPixels

    colorSumBlueSky    = onlySky[:,:,0].sum()
    colorSumGreenSky   = onlySky[:,:,1].sum()
    colorSumRedSky     = onlySky[:,:,2].sum()
    #
    colorSumBlueCloud  = onlyCloud[:,:,0].sum()
    colorSumGreenCloud = onlyCloud[:,:,1].sum()
    colorSumRedCloud   = onlyCloud[:,:,2].sum()
    #
    cloudPixelCount  = np.sum(binaryImage[:,:,0] == 255)
    skyPixelCount    = np.sum(binaryImage[:,:,0] == 0)


    if cloudPercentage !=100:
        averageBlueSky  = colorSumBlueSky/skyPixelCount
        averageGreenSky = colorSumGreenSky/skyPixelCount
        averageRedSky   = colorSumRedSky/skyPixelCount
    else:
        averageBlueSky  = -1  # Denoting 0% of Sky
        averageGreenSky = -1  # Denoting 0% of Sky
        averageRedSky   = -1  # Denoting 0% of Sky

# Printing the Average Pixel values for each Color

    if  cloudPercentage !=0:
        averageBlueCloud  = colorSumBlueCloud/cloudPixelCount
        averageGreenCloud = colorSumGreenCloud/cloudPixelCount
        averageRedCloud   = colorSumRedCloud/cloudPixelCount
    else:
        averageBlueCloud  = -1 # Denoting 0% of Sky
        averageGreenCloud = -1 # Denoting 0% of Sky
        averageRedCloud   = -1 # Denoting 0% of Sky

    cloudPercentage =str(float(cloudPercentage))
    print("------------------------------")
    # print("Predictionn Accuracy :  "+str(percentageAccuracy)+"%")
    print("------------------------------")
    print("Cloud Pecentage      :  "+cloudPercentage+"%")
    print('-----------------------------------')
    print('All Red              : ',averageRedAll)
    print('All Green            : ',averageGreenAll)
    print('All Blue             : ',averageBlueAll)
    print('-----------------------------------')
    print('Sky Red              : ',averageRedSky)
    print('Sky Green            : ',averageGreenSky)
    print('Sky Blue             : ',averageBlueSky)
    print('-----------------------------------')
    print('Cloud Red            : ',averageRedCloud)
    print('Cloud Green          : ',averageGreenCloud)
    print('Cloud Blue           : ',averageBlueCloud)
    print('-----------------------------------')
    print('Done.')


    sensorDictionary = OrderedDict([
            ("dateTime"             ,str(dateTime)),
            ("cloudPecentage"       ,cloudPercentage),
            ("allRed"               ,averageRedAll),
            ("allGreen"             ,averageGreenAll),
            ("allBlue"              ,averageBlueAll),
            ("skyRed"               ,averageRedSky),
            ("skyGreen"             ,averageGreenSky),
            ("skyBlue"              ,averageBlueSky),
            ("cloudRed"             ,averageRedCloud),
            ("cloudGreen"           ,averageGreenCloud),
            ("cloudBlue"            ,averageBlueCloud),
         ])

    return sensorDictionary

def writeBinaryImageXU4NoSave(Pixel_Row ,Image_Shape,PathIn,onboardCapture):
    # Designed to return a binary image and write the said image to a given path
    Image_Reshaped = []
    Pixel_Row_255 = Pixel_Row.astype(float)*255
    Pixel_Row_Transpose = np.transpose(Pixel_Row_255)
    Image_Reshaped_Pre = np.asarray(Pixel_Row_Transpose.reshape((Image_Shape[0], Image_Shape[1])))
    Image_Reshaped     = np.zeros((Image_Shape[0], Image_Shape[1], 3))

    Image_Reshaped[:, :, 0] = Image_Reshaped_Pre
    Image_Reshaped[:, :, 1] = Image_Reshaped_Pre
    Image_Reshaped[:, :, 2] = Image_Reshaped_Pre

    os.remove(PathIn)

    # binaryImagePath = PathIn.replace("SKYCAM", "SKYCAM_binary")
    # directoryCheck(binaryImagePath)
    # cv2.imwrite(binaryImagePath, Image_Reshaped)

    return Image_Reshaped


def getResults(originalImage,binaryImage,predictionBinary,prediction,imagePath):

    onlyCloud          = getCloudOnlyImage(originalImage,binaryImage)
    onlySky            = getSkyOnlyImage(originalImage,binaryImage)
    cloudPercentage    = (sum(predictionBinary)/len(predictionBinary))*100

    percentageAccuracy =sum(abs(prediction-.5)*200)/len(prediction)
    #
    colorSumBlueSky    = onlySky[:,:,0].sum()
    colorSumGreenSky   = onlySky[:,:,1].sum()
    colorSumRedSky     = onlySky[:,:,2].sum()
    #
    colorSumBlueCloud  = onlyCloud[:,:,0].sum()
    colorSumGreenCloud = onlyCloud[:,:,1].sum()
    colorSumRedCloud   = onlyCloud[:,:,2].sum()
    #
    cloudPixelCount  = np.sum(binaryImage[:,:,0] == 255)
    skyPixelCount    = np.sum(binaryImage[:,:,0] == 0)

    if cloudPercentage !=100:
        averageBlueSky  = colorSumBlueSky/skyPixelCount
        averageGreenSky = colorSumGreenSky/skyPixelCount
        averageRedSky   = colorSumRedSky/skyPixelCount
    else:
        averageBlueSky  = -1  # Denoting 0% of Sky
        averageGreenSky = -1  # Denoting 0% of Sky
        averageRedSky   = -1  # Denoting 0% of Sky
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

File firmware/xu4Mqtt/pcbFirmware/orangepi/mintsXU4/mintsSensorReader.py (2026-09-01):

# ***************************************************************************
#  mintsXU4
#   ---------------------------------
#   Written by: Lakitha Omal Harindha Wijeratne
#   - for -
#   Mints: Multi-scale Integrated Sensing and Simulation
#   ---------------------------------
#   Date: February 4th, 2019
#   ---------------------------------
#   This module is written for generic implimentation of MINTS projects
#   --------------------------------------------------------------------------
#   https://github.com/mi3nts
#   http://utdmints.info/
#  ***************************************************************************

import serial
import datetime
import os
import csv
#import deepdish as dd
from mintsXU4 import mintsLatest as mL
from mintsXU4 import mintsDefinitions as mD
from getmac import get_mac_address
import time
import serial
import pynmea2
from collections import OrderedDict
import netifaces as ni
import math
import json
import pandas as pd 
# from mintsPMCorrections import corrections as mC
import traceback

macAddress      = mD.macAddress
dataFolder      = mD.dataFolder
latestDisplayOn = mD.latestDisplayOn
dataFolderMQTT  = mD.dataFolderMQTT
latestOn        = mD.latestOn
mqttOn          = mD.mqttOn
dataFolderTmp   = mD.dataFolderTmp




def sensorFinisher(dateTime,sensorName,sensorDictionary):
    print("-----------------------------------")
    print("-------- Sensor Finisher ----------")
    print(sensorName)
    writePath = getWritePath(sensorName,dateTime)
    exists = directoryCheck(writePath)
    writeCSV2(writePath,sensorDictionary,exists)
    print(writePath)

    if(latestOn):
       mL.writeJSONLatest(sensorDictionary,sensorName)
    if(mqttOn):
       mL.writeMQTTLatest(sensorDictionary,sensorName)   


#    mC.doPrediction(sensorName,sensorDictionary,dateTime)
    print()





def IPS7100WriteI2c(sensorData):
    sensorName = "IPS7100"
    dataLength = 15
    if(len(sensorData) == dataLength):
        sensorDictionary =  OrderedDict([
                ("dateTime"     ,str(sensorData[0])), 
           		("pc0_1"        ,sensorData[1]), 
            	("pc0_3"        ,sensorData[2]),
                ("pc0_5"        ,sensorData[3]),
                ("pc1_0"        ,sensorData[4]),
            	("pc2_5"        ,sensorData[5]),
        		("pc5_0"        ,sensorData[6]),
            	("pc10_0"       ,sensorData[7]),
                ("pm0_1"        ,sensorData[8]),
            	("pm0_3"        ,sensorData[9]),
        		("pm0_5"        ,sensorData[10]), 
            	("pm1_0"        ,sensorData[11]),
                ("pm2_5"        ,sensorData[12]),
            	("pm5_0"        ,sensorData[13]),      
                ("pm10_0"       ,sensorData[14]),
                ])
    sensorFinisher(sensorData[0],sensorName,sensorDictionary) 

def COZIRAEH2000Write(sensorData):
    sensorName = "COZIRAEH2000"
    dataLength = 5
    if(len(sensorData) == dataLength):
        sensorDictionary =  OrderedDict([
                ("dateTime"     ,str(sensorData[0])), 
        		("co2Recent"    ,sensorData[1]),
            	("co2Filtered"  ,sensorData[2]),
                ("temperature"  ,sensorData[3]),
            	("humidity"     ,sensorData[4]),
            	])
        sensorFinisher(sensorData[0],sensorName,sensorDictionary)  

def BME280V3WriteI2c(sensorData):
    sensorName = "BME280V3"
    dataLength = 6
    if(len(sensorData) == dataLength):
        sensorDictionary =  OrderedDict([
                ("dateTime"     ,str(sensorData[0])), 
        		("temperature"  ,sensorData[1]),
            	("pressure"     ,sensorData[2]),
                ("humidity"     ,sensorData[3]),
            	("dewPoint"     ,sensorData[4]),
            	("altitude"     ,sensorData[5])
                ])
        # with open("bme280.csv", "w") as outfile:
            #csvwriter = csv.writer(outfile)
            #csvwriter.writerow(dict(sensorDictionary))
            #csvwriter.writerow(dict(sensorDictionary).values()) # temp write to .csv file REMOVE OR EDIT THIS
        sensorFinisher(sensorData[0],sensorName,sensorDictionary)

# For use with DREAM boards (containing multiple BME280's per board)
def BME280V3WriteI2cDREAM(sensorData, sensorName):
    dataLength = 6
    if(len(sensorData) == dataLength):
        sensorDictionary =  OrderedDict([
                ("dateTime"     ,str(sensorData[0])), 
        		("temperature"  ,sensorData[1]),
            	("pressure"     ,sensorData[2]),
                ("humidity"     ,sensorData[3]),
            	("dewPoint"     ,sensorData[4]),
            	("altitude"     ,sensorData[5])
                ])
        # with open("bme280.csv", "w") as outfile:
            #csvwriter = csv.writer(outfile)
            #csvwriter.writerow(dict(sensorDictionary))
            #csvwriter.writerow(dict(sensorDictionary).values()) # temp write to .csv file REMOVE OR EDIT THIS
        sensorFinisher(sensorData[0],sensorName,sensorDictionary)    

def BME280Write(sensorData,dateTime):
    dataOut    = sensorData.split(':')
    sensorName = "BME280"
    dataLength = 4
    if(len(dataOut) == (dataLength +1)):
        sensorDictionary =  OrderedDict([
                ("dateTime"     , str(dateTime)), # always the same
        		("temperature"  ,dataOut[0]), # check with arduino code
            	("pressure"     ,dataOut[1]),
                ("humidity"     ,dataOut[2]),
            	("altitude"     ,dataOut[3])
                ])
        sensorFinisher(dateTime,sensorName,sensorDictionary)

def delayMints(timeSpent,loopIntervalIn):
    loopIntervalReal = loopIntervalIn ;
    if(loopIntervalReal>timeSpent):
        waitTime = loopIntervalReal - timeSpent;
        time.sleep(waitTime);
    return time.time();

def sensorFinisherReference(dateTime,sensorName,sensorDictionary):
    # Getting Write Path
    print("-----------------------------------")
    writePath = getWritePathReference(sensorName,dateTime)
    exists    = directoryCheck(writePath)
    writeCSV2(writePath,sensorDictionary,exists)
    print(writePath)
    if(latestDisplayOn):
       mL.writeJSONLatestReference(sensorDictionary,sensorName)
    print(sensorName)
    print(sensorDictionary)
    print("-----------------------------------")


def sensorFinisherIP(dateTime,sensorName,sensorDictionary):
    #Getting Write Path
    writePath = getWritePathIP(sensorName,dateTime)
    exists = directoryCheck(writePath)
    writeCSV2(writePath,sensorDictionary,exists)
    print(writePath)
    if(latestDisplayOn):
       mL.writeJSONLatest(sensorDictionary,sensorName)
    if(mqttOn):
       mL.writeMQTTLatest(sensorDictionary,sensorName)   
        
    print("-----------------------------------")
    print(sensorName)
    print(sensorDictionary)

def dataSplit(dataString,dateTime):
    dataOut   = dataString.split('!')
    if(len(dataOut) == 2):
        tag       = dataOut[0]
        dataQuota = dataOut[1]
        if(tag.find("#mintsO")==0):
            sensorSplit(dataQuota,dateTime)
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

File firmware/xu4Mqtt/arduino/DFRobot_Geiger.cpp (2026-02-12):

/*!
 *@file DFRobot_Geiger.cpp
 *@brief Define the basic structure of class DFRobot_Geiger, the implementation of the basic methods
 *@copyright   Copyright (c) 2010 DFRobot Co.Ltd (http://www.dfrobot.com)
 *@licence     The MIT License (MIT)
 *@author [fengli](li.feng@dfrobot.com)
 *@version  V1.0
 *@date  2021-9-14
 *@get from https://www.dfrobot.com
 *@https://github.com/DFRobot/DFRobot_Geiger
*/

#include <DFRobot_Geiger.h>
long numPulse1;
long numPulse2;
long numPulse3;
DFRobot_Geiger::DFRobot_Geiger(int pin)
{
  _intPin = pin;
  startMeasure = false;
}

void Geigeisr(){
	numPulse1++;
	numPulse2++;
	numPulse3++;
}

void DFRobot_Geiger::start()
{
	
  pinMode(_intPin, INPUT);
  attachInterrupt(digitalPinToInterrupt(_intPin),Geigeisr, FALLING);
  startMeasure = true;
  numPulse1 = 0;
  numPulse2 = 0;
  numPulse3 = 0;
  startTime1 = millis();
  startTime2 = startTime1;
  startTime3 = startTime1;
}

void DFRobot_Geiger::pause()
{
  detachInterrupt(digitalPinToInterrupt(_intPin));
  endTime = millis();
  startMeasure = false;
}

uint16_t DFRobot_Geiger::getCPM()
{
  float CPM;
  long minutes;
  static uint8_t pos = 0;
  static uint8_t tail = 0;
  static uint8_t head = 0;
  
  if(startMeasure == false){
     minutes = (endTime - startTime1);
  } else {
	 minutes = (millis() - startTime1); 
     if(pos == 10) refresh1 = true;
  }
  CPM = (60000000)/(minutes-10);
  CPM = CPM/1000;
  //DBG(minutes);
  //DBG(numPulse1);
  CPM = CPM*numPulse1;
//DBG(CPM);
 // if(pos >= 10){
//	  pos = 0;
  //}

  Pulse1[tail] = CPM;
  pos++;
  tail ++;
  tail = (tail)%BUFFER_SIZE;
  
  //DBG(tail);
  if(first1){
	  long numAll = 0;
	  head  = (tail +7)%BUFFER_SIZE;
	  for(uint8_t i = 5 ; i < 8; i++){
		 
		 head++;
		
		 head =(head)%BUFFER_SIZE;
		  //Serial.print(head); Serial.print(" "); 
		 numAll += Pulse1[head];
		 
		 
	  }
	  
	  CPM = numAll / 3;
	  first1 --;
   } 
  
  if(refresh1 == true){
//Serial.println("------------------------");
		startTime1 =  millis();
        numPulse1 = 0;
		refresh1 = false;
		first1 = 3;
		pos = 0;
  }
  return (uint16_t)CPM;
}

uint16_t DFRobot_Geiger::getnSvh()
{
	
  float CPM;
  long minutes;
  static uint8_t pos = 0;
  static uint8_t tail = 0;
  static uint8_t head = 0;
  
  if(startMeasure == false){
     minutes = (endTime - startTime2);
  } else {
	 minutes = (millis() - startTime2); 
     if(pos == 10) refresh2 = true;
  }
  CPM = (60000000)/(minutes-10);
  CPM = CPM/1000;

  CPM = CPM*numPulse2;


  Pulse2[tail] = CPM;
  pos++;
  tail ++;
  tail = (tail)%BUFFER_SIZE;
  
  //DBG(tail);
  if(first2){
	  long numAll = 0;
	  head  = (tail +7)%BUFFER_SIZE;
	  for(uint8_t i = 5 ; i < 8; i++){
		 
		 head++;
		
		 head =(head)%BUFFER_SIZE;
		  //Serial.print(head); Serial.print(" "); 
		 numAll += Pulse2[head];
		 
		 
	  }
	  
	  CPM = numAll / 3;
	  first2 --;
   } 
  
  if(refresh2 == true){
//Serial.println("------------------------");
		startTime2 =  millis();
        numPulse2 = 0;
		refresh2 = false;
		first2 = 3;
		pos = 0;
  }
  //DBG(CPM);
  return (float(CPM/151))*1000;

}

float DFRobot_Geiger::getuSvh()
{
float CPM;
  long minutes;
  static uint8_t pos = 0;
  static uint8_t tail = 0;
  static uint8_t head = 0;
  
  if(startMeasure == false){
     minutes = (endTime - startTime3);
  } else {
	 minutes = (millis() - startTime3); 
     if(pos == 10) refresh3 = true;
  }
  CPM = (60000000)/(minutes-10);
  CPM = CPM/1000;
  //DBG(CPM);
  //DBG(numPulse1);
  CPM = CPM*numPulse3;
  //DBG(CPM);
 // if(pos >= 10){
//	  pos = 0;
  //}

  Pulse3[tail] = CPM;
  pos++;
  tail ++;
  tail = (tail)%BUFFER_SIZE;
  
  //DBG(tail);
  if(first3){
	  long numAll = 0;
	  head  = (tail +7)%BUFFER_SIZE;
	  for(uint8_t i = 5 ; i < 8; i++){
		 
		 head++;
		
		 head =(head)%BUFFER_SIZE;
		  //Serial.print(head); Serial.print(" "); 
		 numAll += Pulse3[head]; 
	  }
	  
	  CPM = numAll / 3;
	  first3 --;
   } 
  
  if(refresh3 == true){
//Serial.println("------------------------");
		startTime3 =  millis();
        numPulse3 = 0;
		refresh3 = false;
		first3 = 3;
		pos = 0;
  }
  
  return (float)CPM/151;
}

uint16_t DFRobot_Geiger::random()
{
return 1;
}

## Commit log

2025-12-15 Initial KiCad project
    [canopySense_take1.kicad_pcb, canopySense_take1.kicad_sch]
2025-12-20 Organize live KiCad project and archive ZIP backups
    [canopySense_take1.kicad_pcb, canopySense_take1.kicad_sch]
2026-02-12 added mSR.sensorFinisher to opcReader
2026-02-12 added gpsReader.py, sen0463Reader.py, restructuring sub-board scripts to pcbFirmware
2026-02-12 added arduino sketch/library
2026-02-15 Added full relay firmware
2026-02-15 Added notes to relayControl
2026-02-19 fixed relayControl; added pcbFirmware/helper libraries
    [bme280Reader.py, cozIRReader.py, i2c_bme280v3.py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]
2026-02-23 trying to fix libraries :(
    [mintsDefinitions.py, mintsSensorReader.py]
2026-02-26 added missing functions to mSR
    [mintsSensorReader.py]
2026-02-26 runAll PCB
2026-03-05 Fixed bugs and added find device by serial id
    [ozoneReader.py, rsFsxcs.py]
2026-03-05 added find device by serial id
2026-03-05 included mintsAudio library
    [labels.csv]
2026-03-05 newer mintsAudio library
    [labels.csv]
2026-03-10 fixed opcReader to include proper fields
    [opcReader.py]
2026-03-22 fixed fatal audio bug, made function camelCase, more Pythonic
    [audioReader.py]
2026-09-01 split pcb file structure
2026-09-01 Added sht40 drivers and reader; install script added and first time setup added to runAll.sh
2026-09-01 initial test pms7003 reader/drivers
2026-09-01 actually uploaded sht40 drivers
2026-09-02 rewrite PMS drivers
